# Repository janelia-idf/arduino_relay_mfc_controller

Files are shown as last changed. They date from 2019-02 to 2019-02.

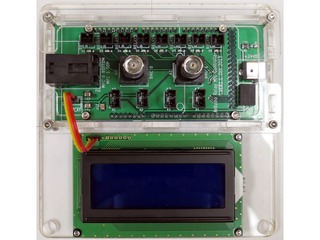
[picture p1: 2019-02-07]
images/arduino_relay_mfc_controller_02_s.jpg

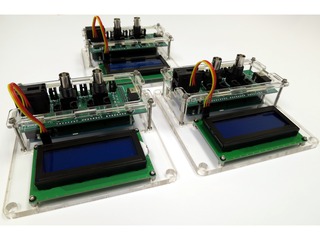
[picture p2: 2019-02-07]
images/arduino_relay_mfc_controller_07_s.jpg

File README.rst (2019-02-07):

============================
Arduino Relay MFC Controller
============================

Arduino-based device to control 24V relays as well as Bronkhorst
IQFlow+ mass flow controllers.

A host PC can send the controller commands through a USB connection or
the controller can be operated standalone with 2 analog signals or 2
potentiometers.

BNC 0 controls the five relays.
0.25V : no relays on
0.75V : relay 0 on
1.25V : relay 1 on
1.75V : relay 2 on
2.25V : relay 3 on
2.75V : relay 4 on
3.25V : relay 5 on
3.75V : relay 6 on
4.25V : relay 7 on

BNC 1 controls the mfc 0 flow rate setting.
The flow rate is set as a percentage of the total mfc capacity.
If the mfc is rated as 1000 sccm, 20% capacity is 200 sccm.
% capacity = (voltage/5)*100
e.g.
0V   : 0%
0.1V : 2%
1V   : 20%
2V   : 40%
3V   : 60%
4V   : 80%
5V   : 100%

firmware
========

Contains the Arduino firmware files. See firmware/README.rst

host
====

Contains the code for controlling with a host computer.

python
------

See host/python/README.rst

pcb
===

Contains the pcb Kicad and gerber files.

Author: Peter Polidoro

This program is free software: you can redistribute it and/or modify
it under the terms of the GNU Lesser General Public License as published by
the Free Software Foundation, either version 3 of the License, or
(at your option) any later version.

This program is distributed in the hope that it will be useful,
but WITHOUT ANY WARRANTY; without even the implied warranty of
MERCHANTABILITY or FITNESS FOR A PARTICULAR PURPOSE.  See the
GNU Lesser General Public License for more details.

You should have received a copy of the GNU Lesser General Public License
along with this program.  If not, see <http://www.gnu.org/licenses/>.

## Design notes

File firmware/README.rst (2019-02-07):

Arduino Relay Mfc Controller Device Firmware
--------------------------------------------

Arduino firmware for the arduino_relay_mfc_controller device.

For see the INSTALL.rst for installation instructions.

arduino_relay_mfc_controller device firmware may be freely distributed
and modified in accordance with the License.

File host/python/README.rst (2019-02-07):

============================
arduino_relay_mfc_controller
============================

arduino_relay_mfc_controller is a python package to control the
Arduino relay mfc controller over USB, using the python module, the
command line, or a webpage using a webserver.

Install
-------

See INSTALL.rst

Python Module
-------------

Typical usage often looks like this::

    from arduino_relay_mfc_controller import ArduinoRelayMfcController, ArduinoRelayMfcControllers

    relay_mfc_controllers = ArduinoRelayMfcControllers()
    device_count = len(relay_mfc_controllers)
    if device_count == 0:
        raise RuntimeError('No Arduino relay mfc controllers detected, check connections.')
    valve_count = relay_mfc_controllers[0].valve_count
    mfc_count = relay_mfc_controllers[0].mfc_count

    o = ArduinoRelayMfcControllers[0]
    o.setMfcFlowRate(mfc=1,percent_capacity=75)
    print o.getMfcFlowRateSetting(mfc=1)
    print o.getMfcFlowRateMeasure(mfc=0)
    o.setRelayOn(4)
    o.setAllRelaysOff()

Web Page Controls
-----------------

Open a terminal and run::

    arduino_relay_mfc_controller_webserver.py

Open a browser and navigate to::

    http://localhost:5000

Author: Peter Polidoro

This program is free software: you can redistribute it and/or modify
it under the terms of the GNU Lesser General Public License as published by
the Free Software Foundation, either version 3 of the License, or
(at your option) any later version.

This program is distributed in the hope that it will be useful,
but WITHOUT ANY WARRANTY; without even the implied warranty of
MERCHANTABILITY or FITNESS FOR A PARTICULAR PURPOSE.  See the
GNU Lesser General Public License for more details.

You should have received a copy of the GNU Lesser General Public License
along with this program.  If not, see <http://www.gnu.org/licenses/>.

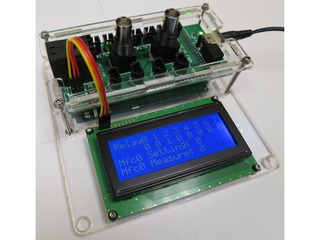
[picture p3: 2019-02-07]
images/arduino_relay_mfc_controller_04_s.jpg

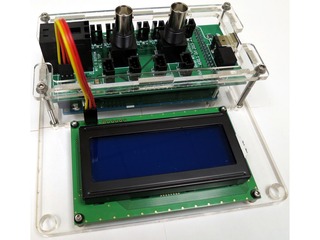
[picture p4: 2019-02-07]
images/arduino_relay_mfc_controller_01_s.jpg

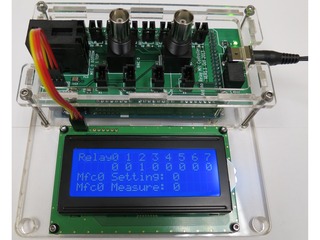
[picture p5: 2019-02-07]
images/arduino_relay_mfc_controller_03_s.jpg

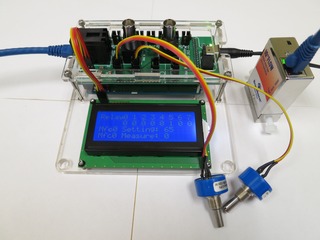
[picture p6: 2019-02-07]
images/arduino_relay_mfc_controller_05_s.jpg

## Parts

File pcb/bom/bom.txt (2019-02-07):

-*- mode:org -*-

# Opt101.lst
| ref     | value                    |
|---------+--------------------------|
| C1      | 0.1uF                    |
| C2      | 0.1uF                    |
| C3      | 10uF                     |
| C4      | 10uF                     |
| C5      | 2.2uF                    |
| C6      | 2.2uF                    |
| C7      | 0.1uF                    |
| C8      | 10uF                     |
| C9      | 1uF                      |
| C10     | 1uF                      |
| C11     | 1uF                      |
| C12     | 1uF                      |
| C13     | 1uF                      |
| D1      | LED                      |
| D2      | LED                      |
| D3      | LED                      |
| D4      | LED                      |
| D5      | LED                      |
| D6      | LED                      |
| D7      | LED                      |
| D8      | LED                      |
| D9      | LED                      |
| D10     | DIODE                    |
| D11     | DIODE                    |
| D12     | DIODE                    |
| D13     | DIODE                    |
| D14     | DIODE                    |
| D15     | DIODE                    |
| D16     | DIODE                    |
| D17     | DIODE                    |
| K1      | A0/D22                   |
| K2      | A1/D23                   |
| K3      | A2/D24                   |
| K4      | A3/D25                   |
| K5      | DISPLAY                  |
| P1      | CONN_POWER               |
| P2      | RELAY0                   |
| P3      | RELAY1                   |
| P4      | RELAY2                   |
| P5      | RELAY3                   |
| P6      | RELAY4                   |
| P7      | RELAY5                   |
| P8      | RELAY6                   |
| P9      | RELAY7                   |
| P10     | RJ45_DOUBLE              |
| P11     | A0/D22                   |
| P12     | A1/D23                   |
| R1      | 1.96k                    |
| REG1    | CONV_DC_DC               |
| RP1     | R_PACK8_2.2k             |
| SHIELD1 | ARDUINO_MEGA_SHIELD_FULL |
| U1      | TLE723X                  |
| U2      | MAX232                   |

# Bill of Materials
| ! | part    | description                      | vendor      | part number               | quantity |   cost |
|---+---------+----------------------------------+-------------+---------------------------+----------+--------|
|   | PCB     | arduino_relay_mfc_control        | pcbuniverse |                           |        1 |   1.00 |
|   | C1-2,7  | CAP CER 0.1UF 50V 10% X7R 1210   | digikey     | 478-3586-1-ND             |        3 |   0.39 |
|   | C3-4,8  | CAP CER 10UF 50V 10% X7S 1210    | digikey     | 445-4536-1-ND             |        3 |   1.24 |
|   | C5-6    | CAP TANT 2.2UF 35V 10% 1210      | digikey     | 478-2414-1-ND             |        2 |   1.25 |
|   | C9-13   | CAP CER 1UF 25V 10% X7R 1210     | digikey     | 445-13383-1-ND            |        5 |   0.84 |
|   | D1-9    | LED GREEN CLEAR 0805 SMD         | digikey     | 160-1179-1-ND             |        9 |   0.35 |
|   | D10-17  | DIODE SCHOTTKY 40V 0.3A SOT23    | digikey     | 497-12131-1-ND            |        8 |   0.54 |
|   | K1-4    | CONN HEADER 3POS .100 VERT GOLD  | digikey     | WM4801-ND                 |        4 |   0.96 |
|   | K5      | LCD SERIAL 4X20 SIDE WHT BKLT    | digikey     | NHD-0420D3Z-NSW-BBW-V3-ND |        1 |  25.90 |
|   | K5      | Jumper Wire - 0.1", 3-pin, 4"    | sparkfun    | PRT-10363                 |        1 |   0.95 |
|   | K5      | CONN HEADER 50POS .100" SGL GOLD | digikey     | SAM1031-50-ND             |        1 |   3.33 |
|   | P1      | CONN PWR JACK DC 2.1X5.5 8A T/H  | digikey     | CP-063AH-ND               |        1 |   1.78 |
|   | P1      | TRANSFORMER DESK TOP 24V 60W     | digikey     | T1208-P5P-ND              |        1 |  26.98 |
|   | P2-9    | CONN HEADER 2POS .100 VERT GOLD  | digikey     | WM4800-ND                 |        8 |   0.88 |
|   | P10     | CONN MOD JACK R/A 8P8C           | digikey     | RJSAE508002-ND            |        1 |   3.86 |
|   | P11-12  | CONN BNC JACK STR 75 OHM PCB     | digikey     | A97565-ND                 |        2 |   2.83 |
|   | R1      | RES 1.96K OHM 1/2W 1% 1210 SMD   | digikey     | 541-1.96KAACT-ND          |        1 |   2.89 |
|   | REG1    | CONV DC/DC 1A 12V OUT SIP VERT   | digikey     | 945-1392-5-ND             |        1 |   8.79 |
|   | RP1     | RES ARRAY 2.2K OHM 8 RES 16SOIC  | digikey     | 767-163-R2.2KP-ND         |        1 |   1.30 |
|   | SHIELD1 | BOARD MCU MEGA2560               | digikey     | 1050-1018-ND              |        1 |  51.91 |
|   | SHIELD1 | CONN HDR VERT 50POS .100" SNGL   | digikey     | SAM1055-50-ND             |        4 |   3.42 |
|   | U1      | IC SW SMART OCTAL LOWSIDE PDSO24 | digikey     | TLE7230GCT-ND             |        1 |   4.62 |
|   | U2      | IC DUAL RS232 ESD-PROT 16-SOIC   | digikey     | 296-26138-1-ND            |        1 |   1.16 |
|---+---------+----------------------------------+-------------+---------------------------+----------+--------|
| # | total   |                                  |             |                           |          | 183.75 |
#+TBLFM: @25$7=(@I$quantity..@II$quantity)*(@I$cost..@II$cost);%.2f;N

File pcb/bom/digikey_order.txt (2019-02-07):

50, 478-3586-1-ND
50, 445-4536-1-ND
50, 478-2414-1-ND
100, 445-13383-1-ND
200, 160-1179-1-ND
200, 497-12131-1-ND
50, WM4801-ND
20, CP-063AH-ND
12, T1208-P5P-ND
200, WM4800-ND
20, RJSAE508002-ND
50, A97565-ND
50, 541-1.96KAACT-ND
20, 945-1392-5-ND
20, 767-163-R2.2KP-ND
10, 1050-1018-ND
30, SAM1031-50-ND
20, TLE7230GCT-ND
20, 296-26138-1-ND

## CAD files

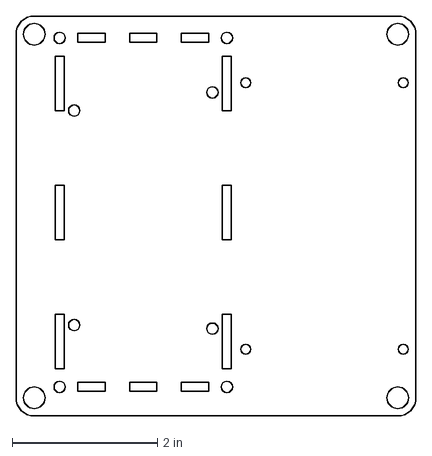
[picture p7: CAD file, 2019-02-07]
enclosure/arduino_relay_mfc_controller_enclosure_display.25in.dxf
5.50 x 5.50 in

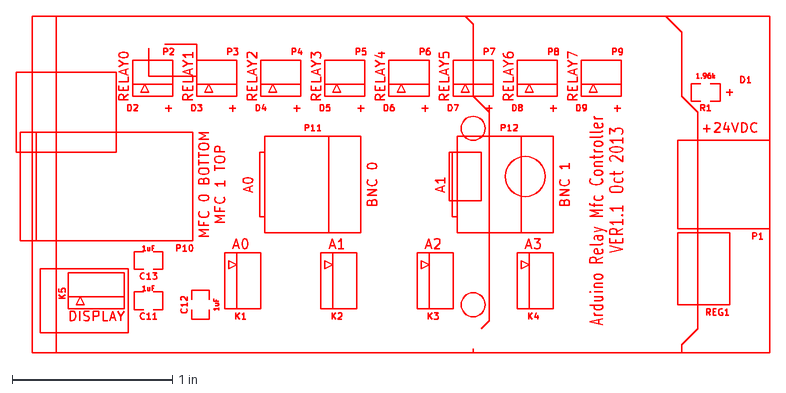
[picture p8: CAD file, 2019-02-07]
pcb/v1.1/dxf/arduino_relay_mfc_controller-SilkS_Front.dxf
4.70 x 2.10 in

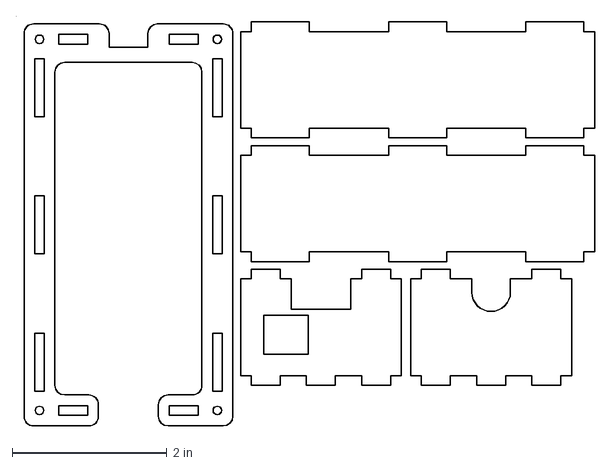
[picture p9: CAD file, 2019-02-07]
enclosure/arduino_relay_mfc_controller_enclosure.125in.dxf
7.48 x 5.30 in

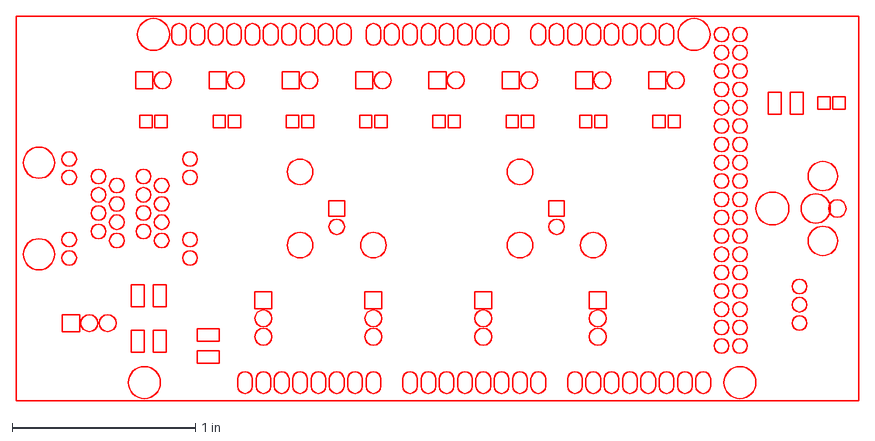
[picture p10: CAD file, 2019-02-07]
pcb/v1.1/dxf/arduino_relay_mfc_controller-Mask_Front.dxf
4.60 x 2.10 in

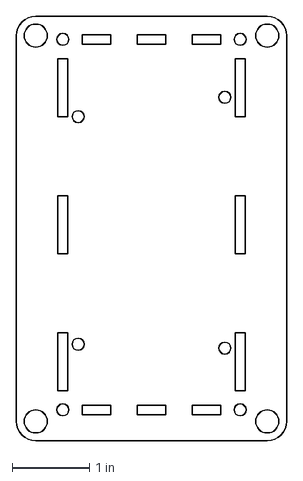
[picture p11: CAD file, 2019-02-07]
enclosure/arduino_relay_mfc_controller_enclosure.25in.dxf
3.50 x 5.50 in

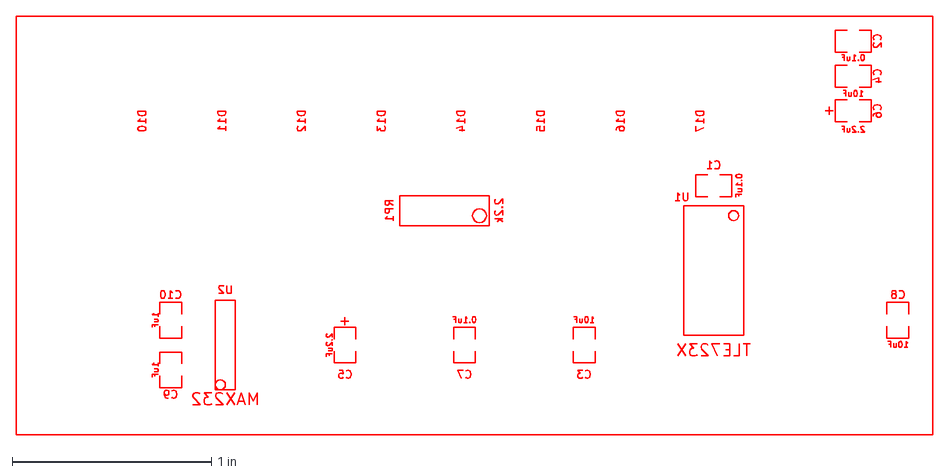
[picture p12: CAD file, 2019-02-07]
pcb/v1.1/dxf/arduino_relay_mfc_controller-SilkS_Back.dxf
4.60 x 2.10 in

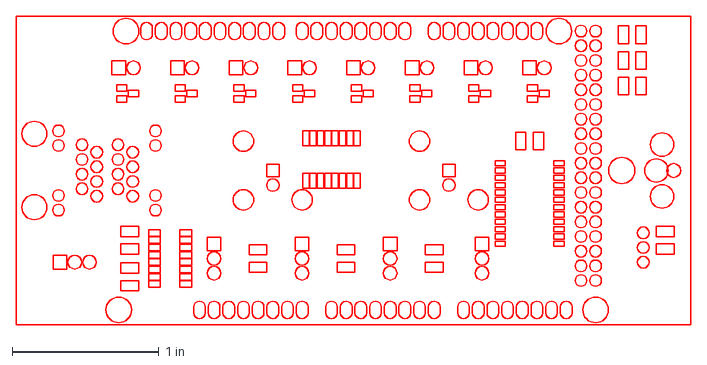
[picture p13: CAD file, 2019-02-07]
pcb/v1.1/dxf/arduino_relay_mfc_controller-Mask_Back.dxf
4.60 x 2.10 in

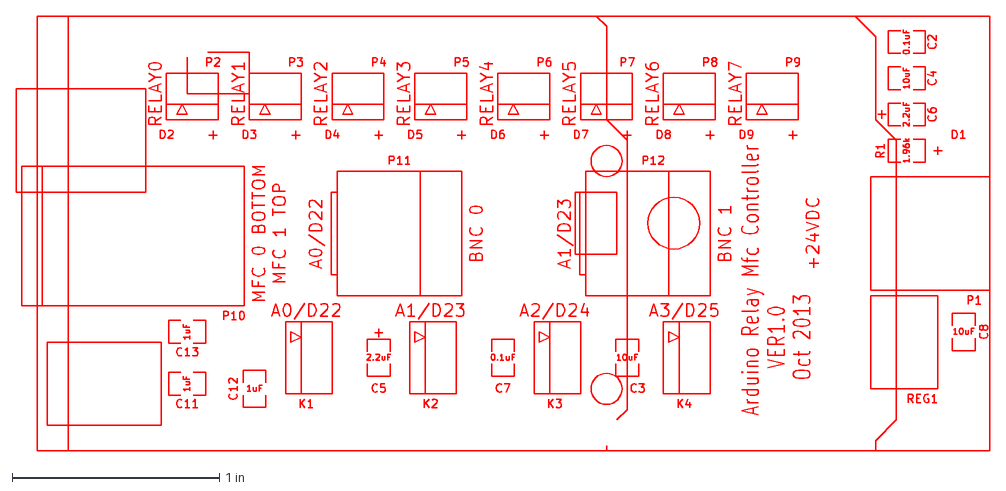
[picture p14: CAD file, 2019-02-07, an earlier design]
pcb/v1.0/dxf/arduino_relay_mfc_controller-SilkS_Front.dxf
4.70 x 2.10 in

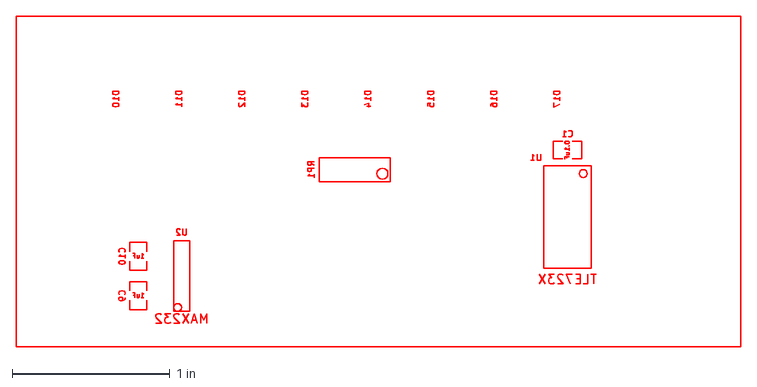
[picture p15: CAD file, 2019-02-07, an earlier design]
pcb/v1.0/dxf/arduino_relay_mfc_controller-SilkS_Back.dxf
4.60 x 2.10 in

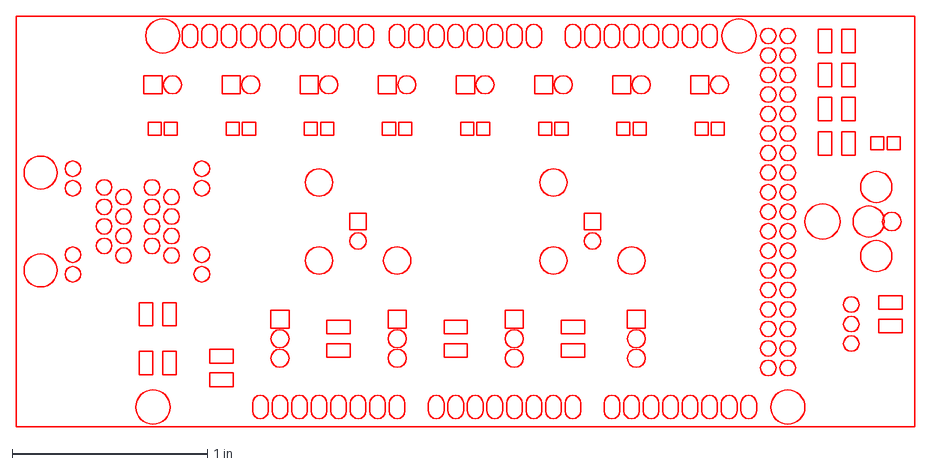
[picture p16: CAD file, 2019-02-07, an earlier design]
pcb/v1.0/dxf/arduino_relay_mfc_controller-Mask_Front.dxf
4.60 x 2.10 in

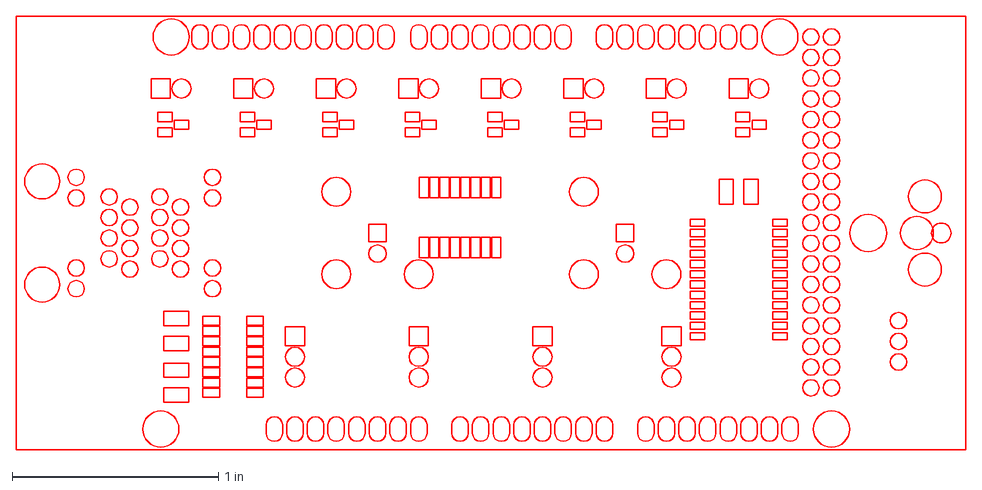
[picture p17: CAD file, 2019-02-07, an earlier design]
pcb/v1.0/dxf/arduino_relay_mfc_controller-Mask_Back.dxf
4.60 x 2.10 in

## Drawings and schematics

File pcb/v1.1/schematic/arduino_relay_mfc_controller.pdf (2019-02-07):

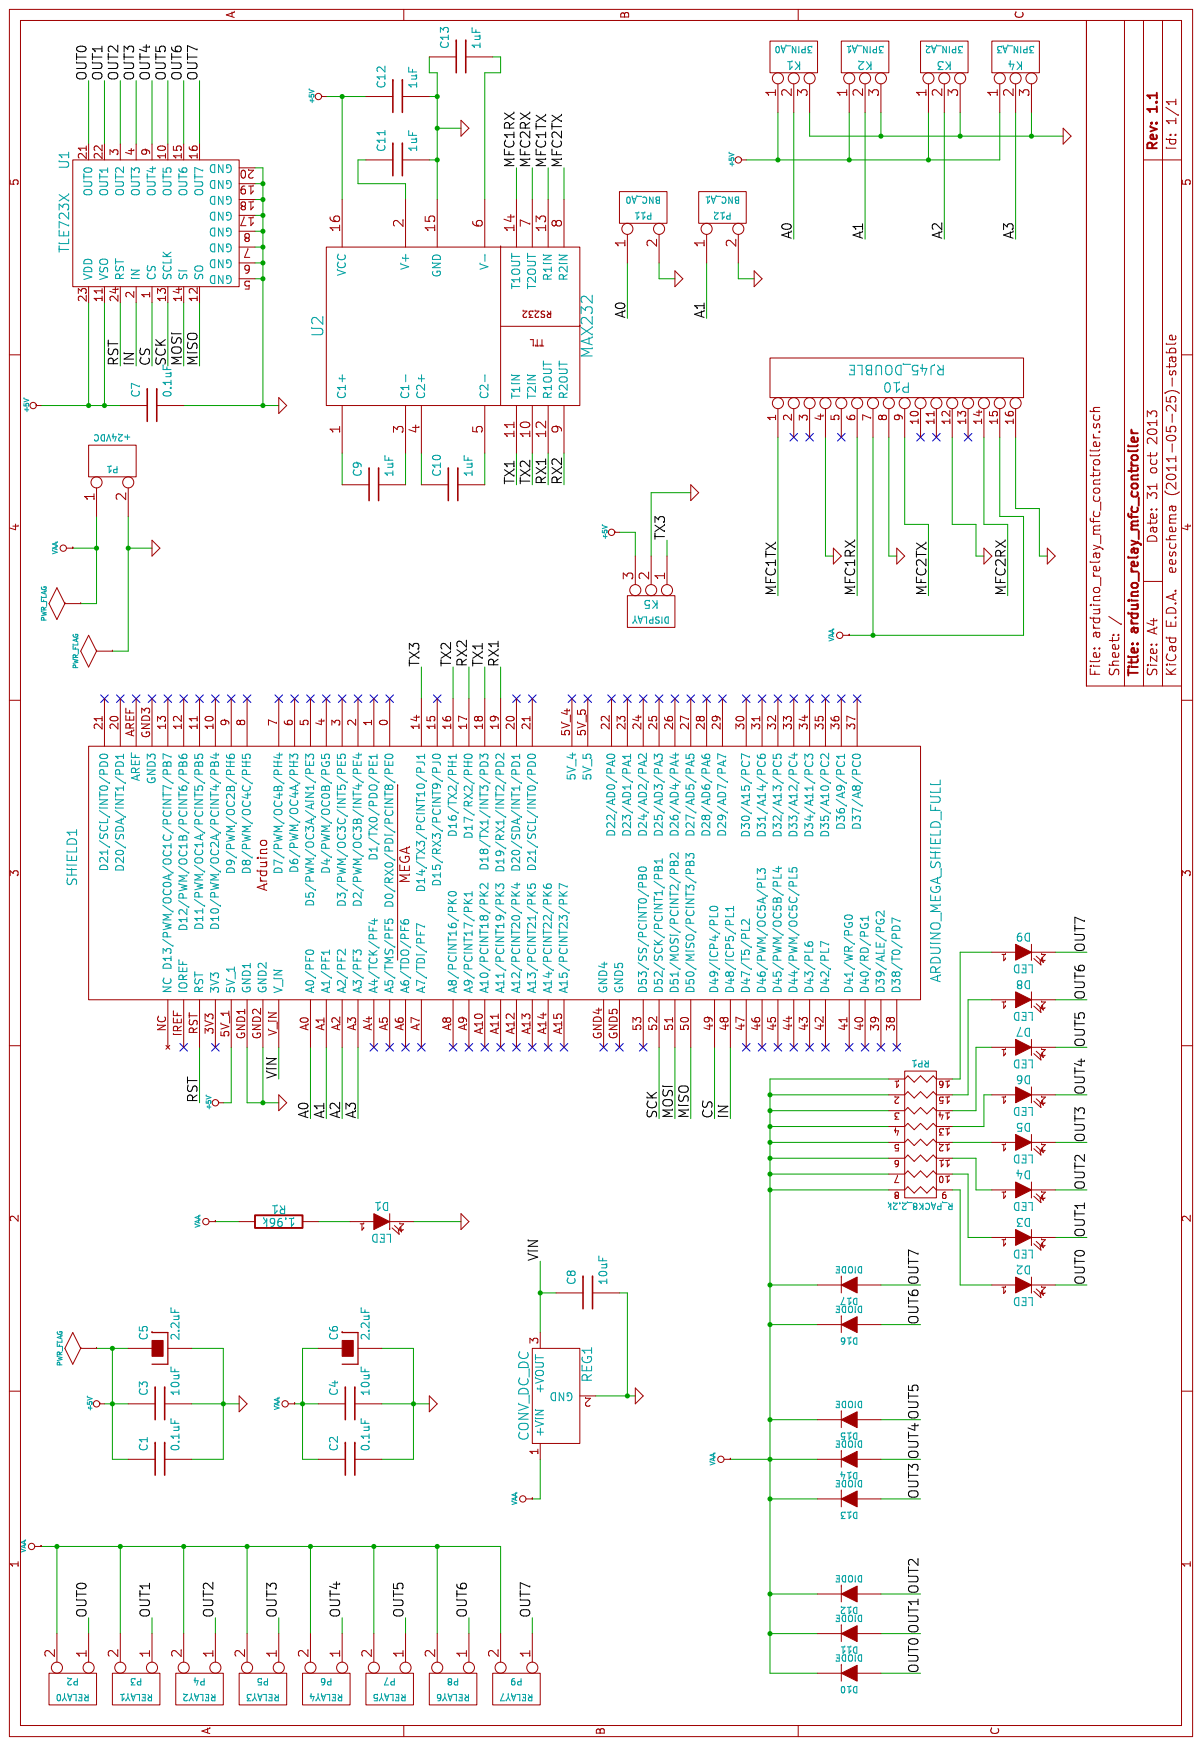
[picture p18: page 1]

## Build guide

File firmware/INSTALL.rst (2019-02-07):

Firmware installation instructions
-----------------------------------

Requirements:

The following libraries should be placed in the arduino sketchbook libraries
directory.

* Streaming              https://bitbucket.org/peterpolidoro/arduino_libs/src
* SerialReceiver         https://bitbucket.org/peterpolidoro/arduino_libs/src
* DictPrinter            https://bitbucket.org/peterpolidoro/arduino_libs/src
* Tle7232g               https://bitbucket.org/peterpolidoro/arduino_libs/src
* Bronkhorst             https://bitbucket.org/peterpolidoro/arduino_libs/src
* TimeTriggeredScheduler https://bitbucket.org/peterpolidoro/arduino_libs/src

Build and upload the firmware using the Arduino IDE.

see http://arduino.cc/en/Guide/Environment for instructions on using the IDE.

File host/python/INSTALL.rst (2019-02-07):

arduino_relay_mfc_controller installation instructions
------------------------------------------------------

* Create a new virtual environment if necessary::

    virtualenv --system-site-packages ~/virtualenvs/arduino_relay_mfc_controller

* Activate a virtual environment::

    source ~/virtualenvs/arduino_relay_mfc_controller/bin/activate

* Install dependencies::

    pip install flask --upgrade
    pip install flask-sijax --upgrade

* Clone bitbucket mercurial repositories::

    mkdir ~/mercurial
    cd ~/mercurial
    hg clone https://bitbucket.org/peterpolidoro/python_libs/
    hg clone https://bitbucket.org/peterpolidoro/arduino_relay_mfc_controller/

* Install python packages::

    cd ~/mercurial/python_libs/arduino_device
    python cleanup.py
    python setup.py install
    cd ~/mercurial/arduino_relay_mfc_controller/host/python
    python cleanup.py
    python setup.py install

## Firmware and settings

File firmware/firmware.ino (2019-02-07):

#include <SPI.h>
#include <Streaming.h>
#include <EEPROM.h>
#include <util/atomic.h>

#include "SerialReceiver.h"
#include "DictPrinter.h"
#include "Tle7232g.h"
#include "Bronkhorst.h"
#include "TimeTriggeredScheduler.h"
#include "NewhavenDisplay.h"
#include "TimerThree.h"

#include "constants.h"
#include "SystemState.h"
#include "MessageHandler.h"

void setup() {
    Serial.begin(constants::baudrate);
    systemState.initialize();
}

void loop() {
    messageHandler.processMsg();
    systemState.updateDisplay();
}
